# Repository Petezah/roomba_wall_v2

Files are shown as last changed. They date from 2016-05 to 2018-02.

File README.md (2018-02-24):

# roomba_wall_v2

An AVR device, based on ATTiny85, to transmit a virtual wall signal for an iRobot Roomba

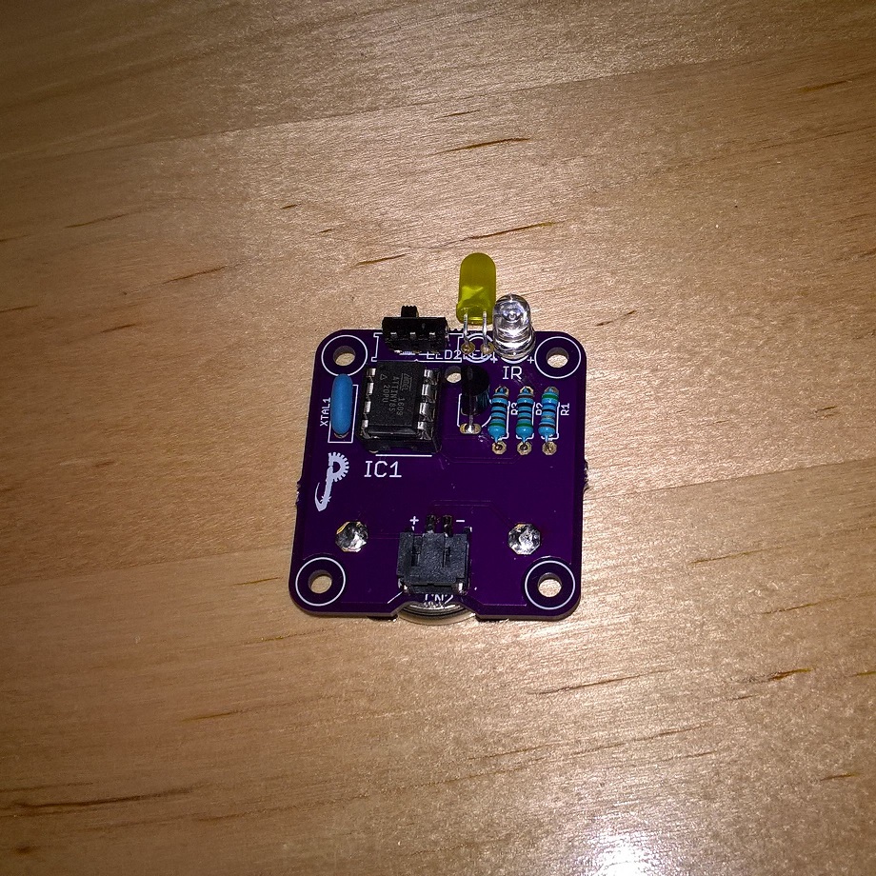
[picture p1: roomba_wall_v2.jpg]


## Folder layout

* /firmware
  * Source for the ATTiny85 firmware
* /hardware
  * Files describing the board layout, etc
* /christmas_tree_barrier
  * Files describing the board layout for the Christmas tree barrier variation

## Building

### Prerequisites for "happy path":

* Raspberry Pi configured with BCM SPI enabled
* AVR-GCC installed
  *  Easiest way to get this is 'sudo apt-get install arduino'
* Either:
  * A 6-position, dual-row IDC cable (recommended)
  * Or jumpers to wire SPI bus of Raspberry Pi to the ISP pads on the finished board

### Steps

#### hardware

* Order a board based on the files in https://github.com/Petezah/roomba_wall_v2/tree/master/hardware
  * Alternately, order one directly from OSH Park here: https://oshpark.com/shared_projects/yCviCn7Z
* Purchase parts from [Mouser electronics](http://mouser.com) using the current BOM
  * Use the ones with "mouser" in their filenames
* Assemble the board--parts are all marked on the silkscreen
  * NB: The ISP header should not be soldered to the board--merely insert the header pins into the IDC cable and wedge the pins into the vias during programming

#### firmware

There are two methods to wire the board for programming:

* *Recommended way*:
  *  Order my Raspberry Pi ISP board here: https://oshpark.com/shared_projects/iYtnPahC
  *  Assemble, and use an IDC cable as described above

* Alternate way: 
  * Hook up the ISP pins on the assembled board to your Raspberry PI as follows:
    * ISP Pin 1 --> Raspberry Pi Pin 21 (MISO)
    * ISP Pin 2 --> Raspberry Pi Pin 17 (3.3V)
    * ISP Pin 3 --> Raspberry Pi Pin 23 (SCK)
    * ISP Pin 4 --> Raspberry Pi Pin 19 (MOSI)
    * ISP Pin 5 --> Raspberry Pi Pin 15 (GPIO22)
    * ISP Pin 6 --> Raspberry Pi Pin 25 (GND)

Once wiring is accomplished:
* Execute the following on the Raspberry Pi command line
  * cd firmware
  * make fuse
  * make install

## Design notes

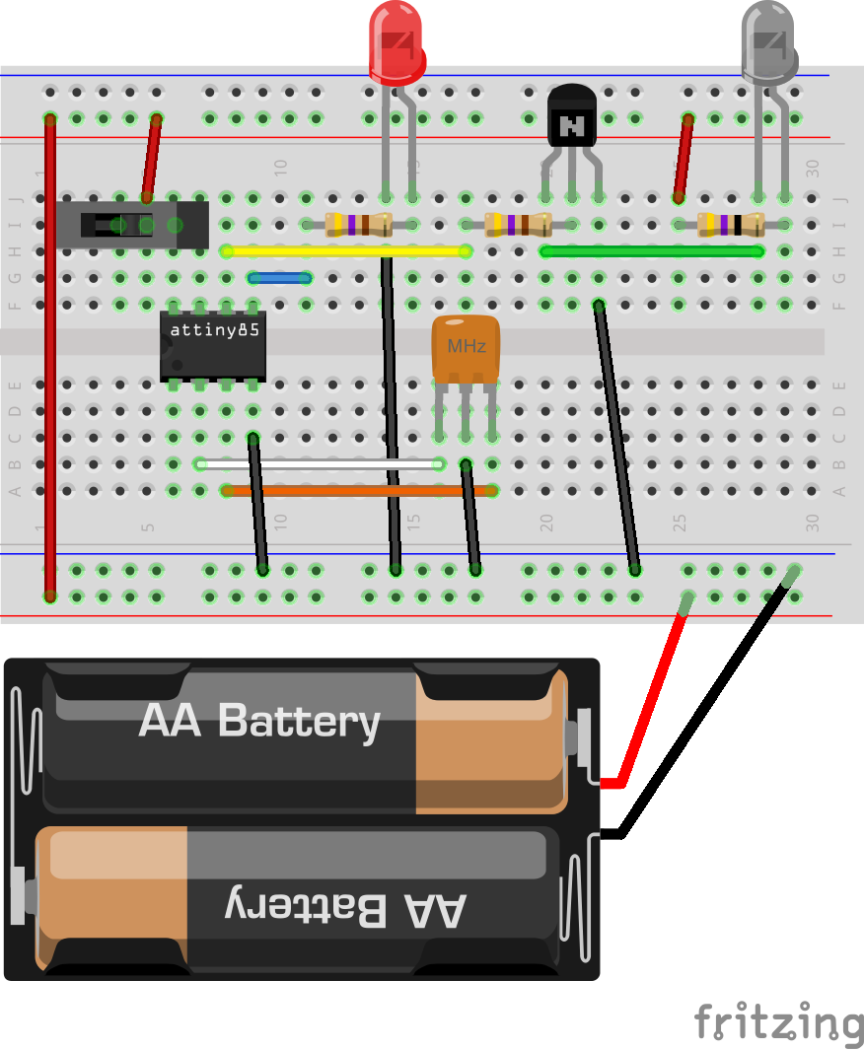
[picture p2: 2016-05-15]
misc/roomba_wall_v2_bb.png

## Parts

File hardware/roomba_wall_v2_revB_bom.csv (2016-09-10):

Mouser # | Mfr. # | Manufacturer | Desc. | RoHS | Lifecycle | Customer Part # | Order Qty. | Price (USD) | Ext.: (USD)
81-CSTLS8M00G53-A0 | CSTLS8M00G53-A0 | Murata | Resonators 8.000MHZ .5% LEADED | RoHS Compliant |  |  | 1 | $0.21 | $0.21
642-MHSS1105 | MHSS1105 | Apem | Slide Switches Microminiature slide SP DT | RoHS Compliant |  |  | 1 | $0.60 | $0.60
12BH003-GR | 12BH003-GR | Eagle Plastic Devices | Coin Cell Battery Holders CR2032 BATTERY CLIP | RoHS Compliant |  |  | 1 | $0.45 | $0.45
512-PN2222ABU | PN2222ABU | Fairchild Semiconductor | Bipolar Transistors - BJT NPN Transistor General Purpose | RoHS Compliant |  |  | 1 | $0.21 | $0.21
660-MF1/4LCT52R510J | MF1/4LCT52R510J | KOA Speer | Metal Film Resistors - Through Hole 1/4 WATT 51 OHM 5% | RoHS Compliant |  |  | 1 | $0.10 | $0.10
660-MF1/4LCT52R561J | MF1/4LCT52R561J | KOA Speer | Metal Film Resistors - Through Hole 1/4 WATT 560 OHM 5% | RoHS Compliant |  |  | 2 | $0.10 | $0.20
941-C566DBFECU0W0351 | C566D-BFE-CU0W0351 | Cree, Inc. | Standard LEDs - Through Hole Blue Oval | RoHS Compliant |  |  | 1 | $0.19 | $0.19
538-10-89-7062 | 10-89-7062 | Molex | Headers & Wire Housings VERT BRKAWAY HDR 6P CN | RoHS Compliant |  |  | 1 | $0.70 | $0.70
782-TSAL6100 | TSAL6100 | Vishay | Infrared Emitters 10 Degree 40mW | RoHS Compliant |  |  | 1 | $0.48 | $0.48
556-ATTINY85-20PU | ATTINY85-20PU | Atmel | 8-bit Microcontrollers - MCU 8kB Flash 0.512kB EEPROM 6 I/O Pins | RoHS Compliant |  |  | 1 | $2.35 | $2.35
485-1769 | 1769 | Adafruit | Adafruit Accessories JST-PH 2-pin SMT Right Angle Connect | RoHS Compliant |  |  | 1 | $0.75 | $0.75

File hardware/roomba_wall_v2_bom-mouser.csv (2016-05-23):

Roomba Virtual Wall v2 - Rev A
Mouser # | Mfr. # | Manufacturer | Desc. | RoHS | Lifecycle | Customer Part # | Order Qty. | Price (USD) | Ext.: (USD)
81-CSTLS8M00G53-A0 | CSTLS8M00G53-A0 | Murata | Resonators 8.000MHZ .5% LEADED | RoHS Compliant |  |  | 1 | $0.23 | $0.23
642-MHSS1105 | MHSS1105 | Apem | Slide Switches Microminiature slide SP DT | RoHS Compliant |  |  | 1 | $0.60 | $0.60
658-CR2032 | CR2032 | Panasonic | Coin Cell Battery 3V 20X3.2MM 225mAH | Not Applicable |  |  | 1 | $0.33 | $0.33
12BH003-GR | 12BH003-GR | Eagle Plastic Devices | Coin Cell Battery Holders CR2032 BATTERY CLIP | RoHS Compliant |  |  | 1 | $0.45 | $0.45
512-PN2222ABU | PN2222ABU | Fairchild Semiconductor | Bipolar Transistors - BJT NPN Transistor General Purpose | RoHS Compliant |  |  | 1 | $0.21 | $0.21
660-MF1/4LCT52R510J | MF1/4LCT52R510J | KOA Speer | Metal Film Resistors - Through Hole 1/4 WATT 51 OHM 5% | RoHS Compliant |  |  | 1 | $0.10 | $0.10
660-MF1/4LCT52R561J | MF1/4LCT52R561J | KOA Speer | Metal Film Resistors - Through Hole 1/4 WATT 560 OHM 5% | RoHS Compliant |  |  | 2 | $0.10 | $0.20
941-C566DBFECU0W0351 | C566D-BFE-CU0W0351 | Cree, Inc. | Standard LEDs - Through Hole Blue Oval | RoHS Compliant |  |  | 1 | $0.19 | $0.19
604-WP7113GD | WP7113GD | Kingbright | Standard LEDs - Through Hole GREEN DIFFUSED | RoHS Compliant |  |  | 1 | $0.14 | $0.14
538-10-89-7062 | 10-89-7062 | Molex | Headers & Wire Housings VERT BRKAWAY HDR 6P CN | RoHS Compliant |  |  | 1 | $0.67 | $0.67
782-TSAL6100 | TSAL6100 | Vishay | Infrared Emitters 10 Degree 40mW | RoHS Compliant |  |  | 1 | $0.48 | $0.48
556-ATTINY85-20PU | ATTINY85-20PU | Atmel | 8-bit Microcontrollers - MCU 8kB Flash 0.512kB EEPROM 6 I/O Pins | RoHS Compliant |  |  | 1 | $1.67 | $1.67
485-1769 | 1769 | Adafruit | Adafruit Accessories JST-PH 2-pin SMT Right Angle Connect | RoHS Compliant |  |  | 1 | $0.75 | $0.75
490-PJ-002A | PJ-002A | CUI Inc. | DC Power Connectors Power Jacks | RoHS Compliant | New At Mouser |  | 1 | $0.93 | $0.93

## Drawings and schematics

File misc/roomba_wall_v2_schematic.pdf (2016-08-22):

A

1 | 2 | 3 | 4 | 5 | 6 | 7 | 8

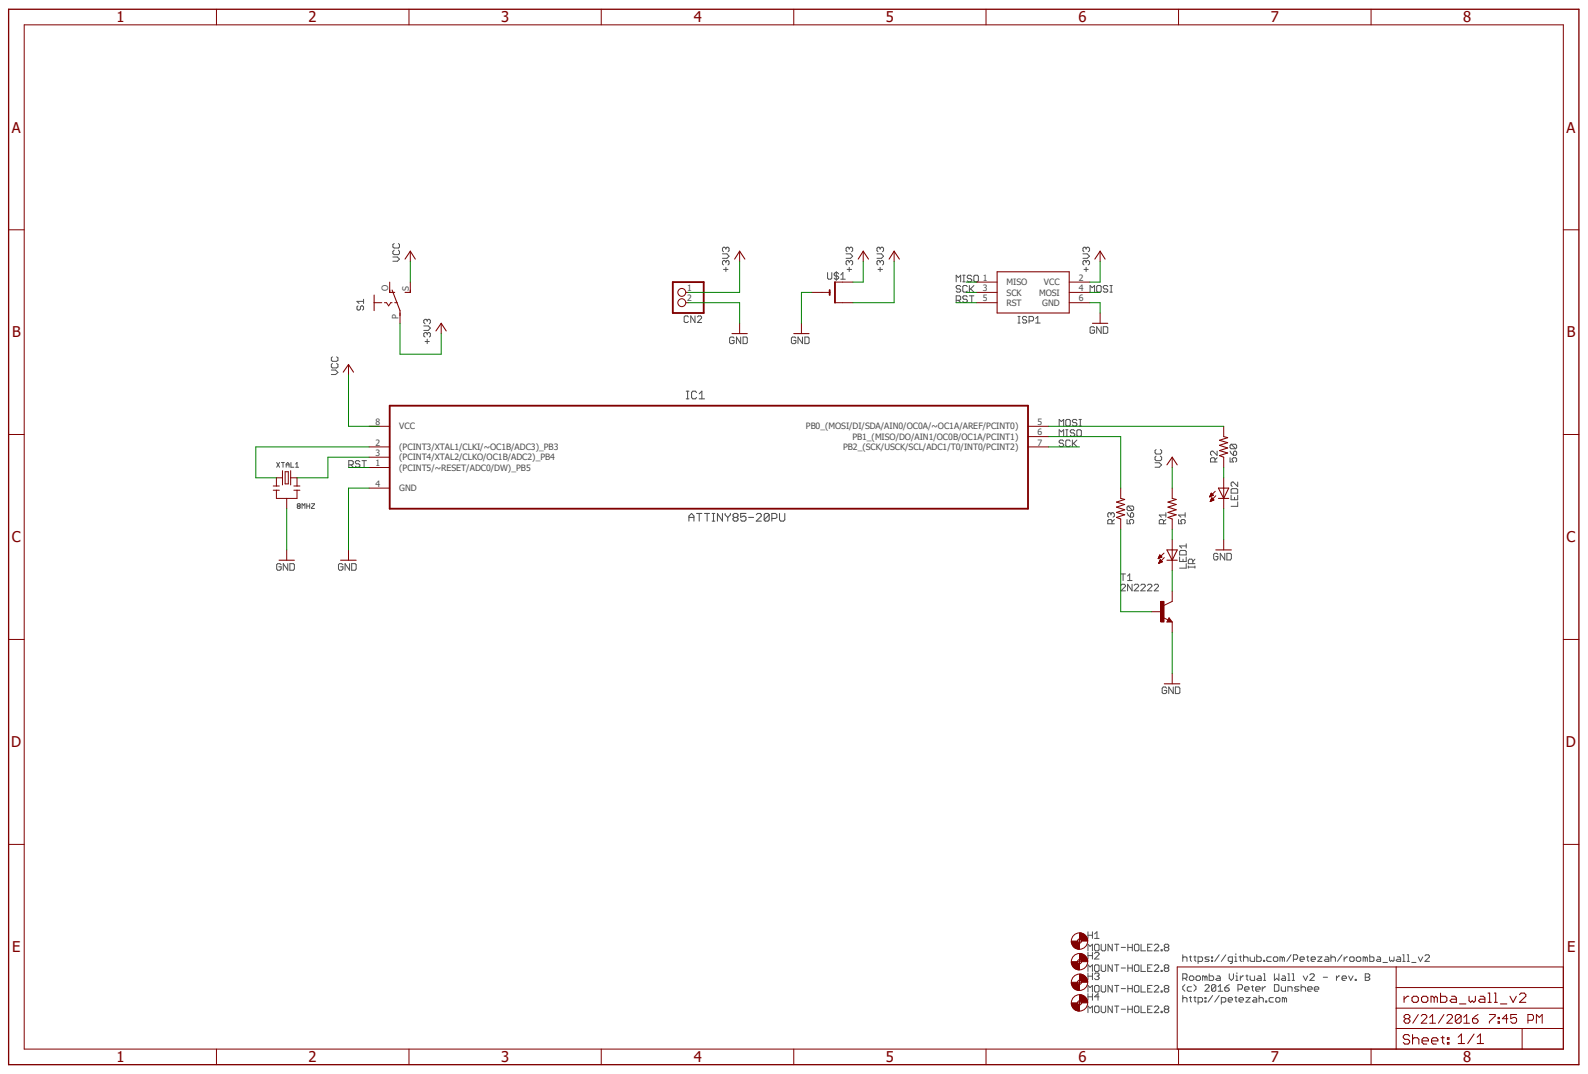
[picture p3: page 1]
VCC 8; (PCINT3/XTAL1/CLKI/~OC1B/ADC3)_PB3 2 (PCINT4/XTAL2/CLKO/OC1B/ADC2)_PB4 3; (PCINT5/~RESET/ADC0/DW)_PB5 1; GND 4; PB0_(MOSI/DI/SDA/AIN0/OC0A/~OC1A/AREF/PCINT0); 5 PB1_(MISO/DO/AIN1/OC0B/OC1A/PCINT1); 6 PB2_(SCK/USCK/SCL/ADC1/T0/INT0/PCINT2); 7 MISO 1; SCK 3; RST 5; GND; 6 MOSI; 4 VCC

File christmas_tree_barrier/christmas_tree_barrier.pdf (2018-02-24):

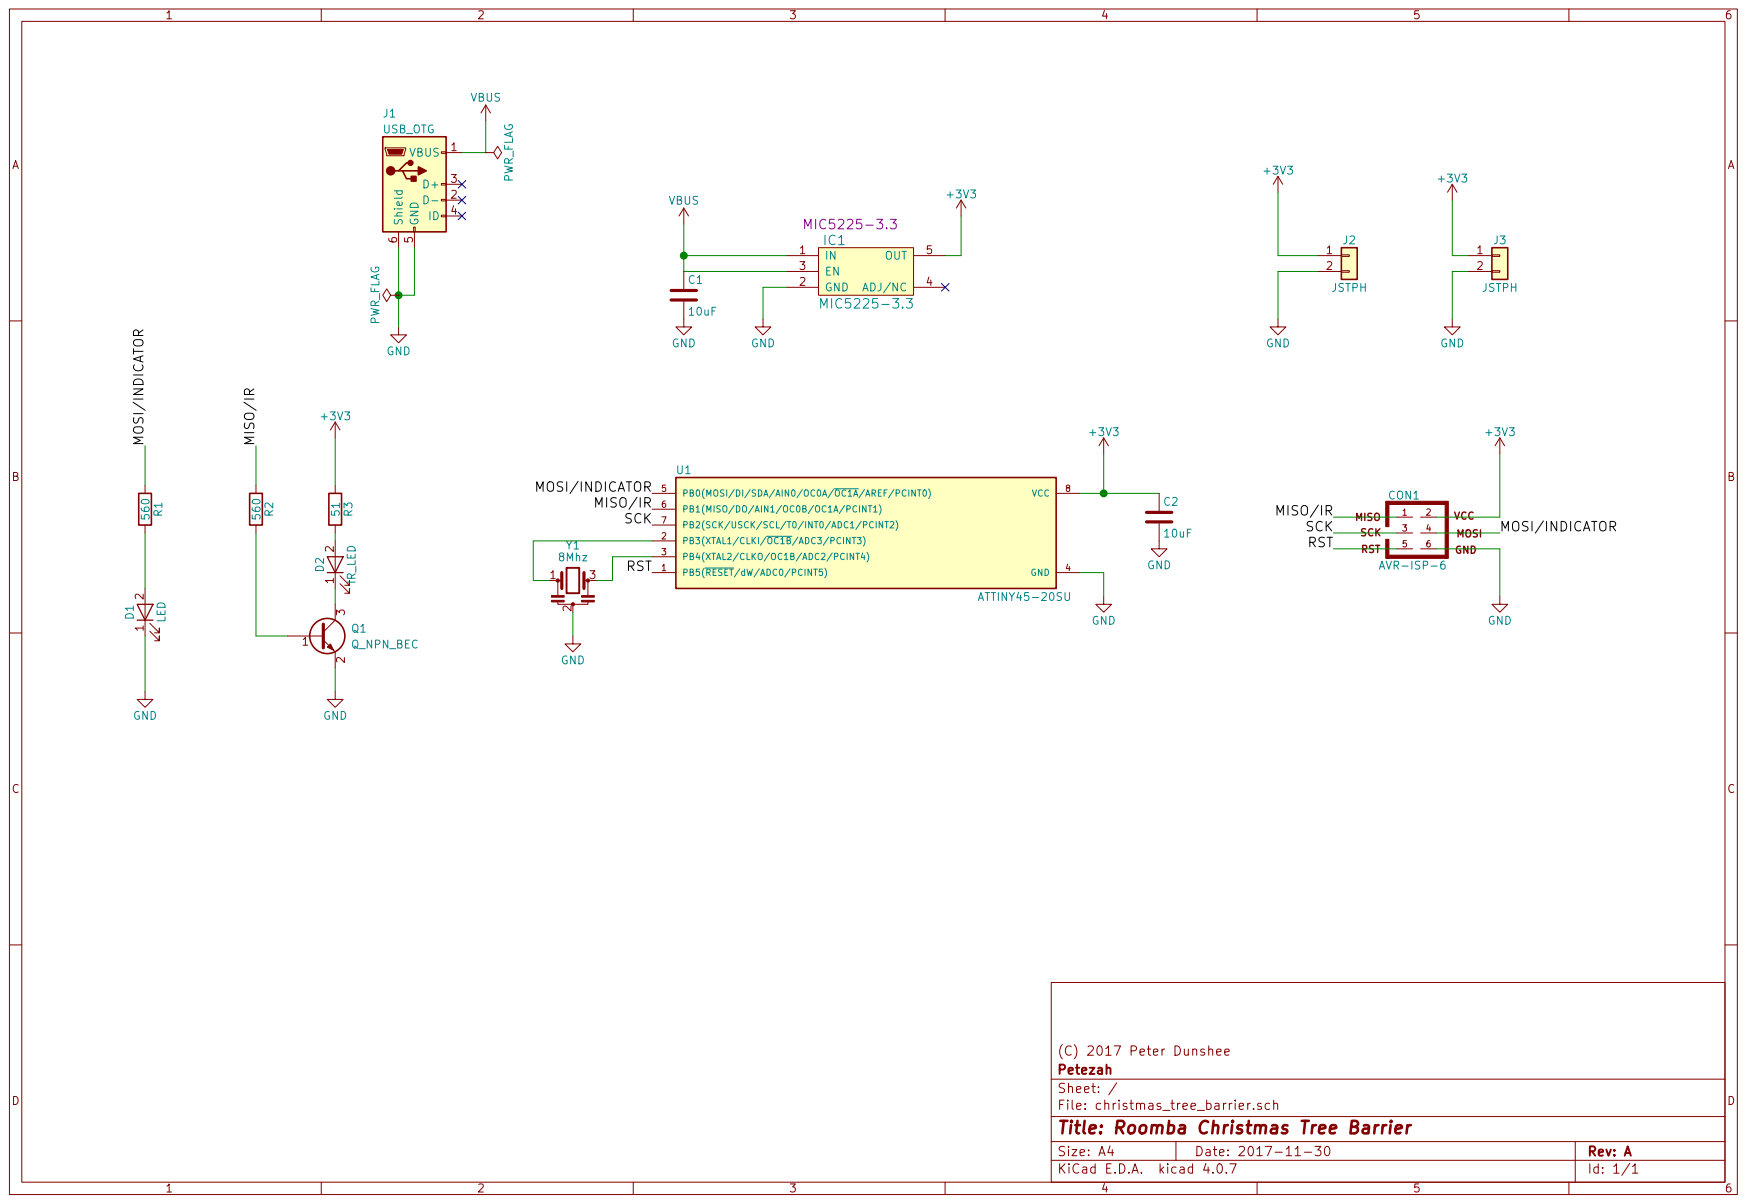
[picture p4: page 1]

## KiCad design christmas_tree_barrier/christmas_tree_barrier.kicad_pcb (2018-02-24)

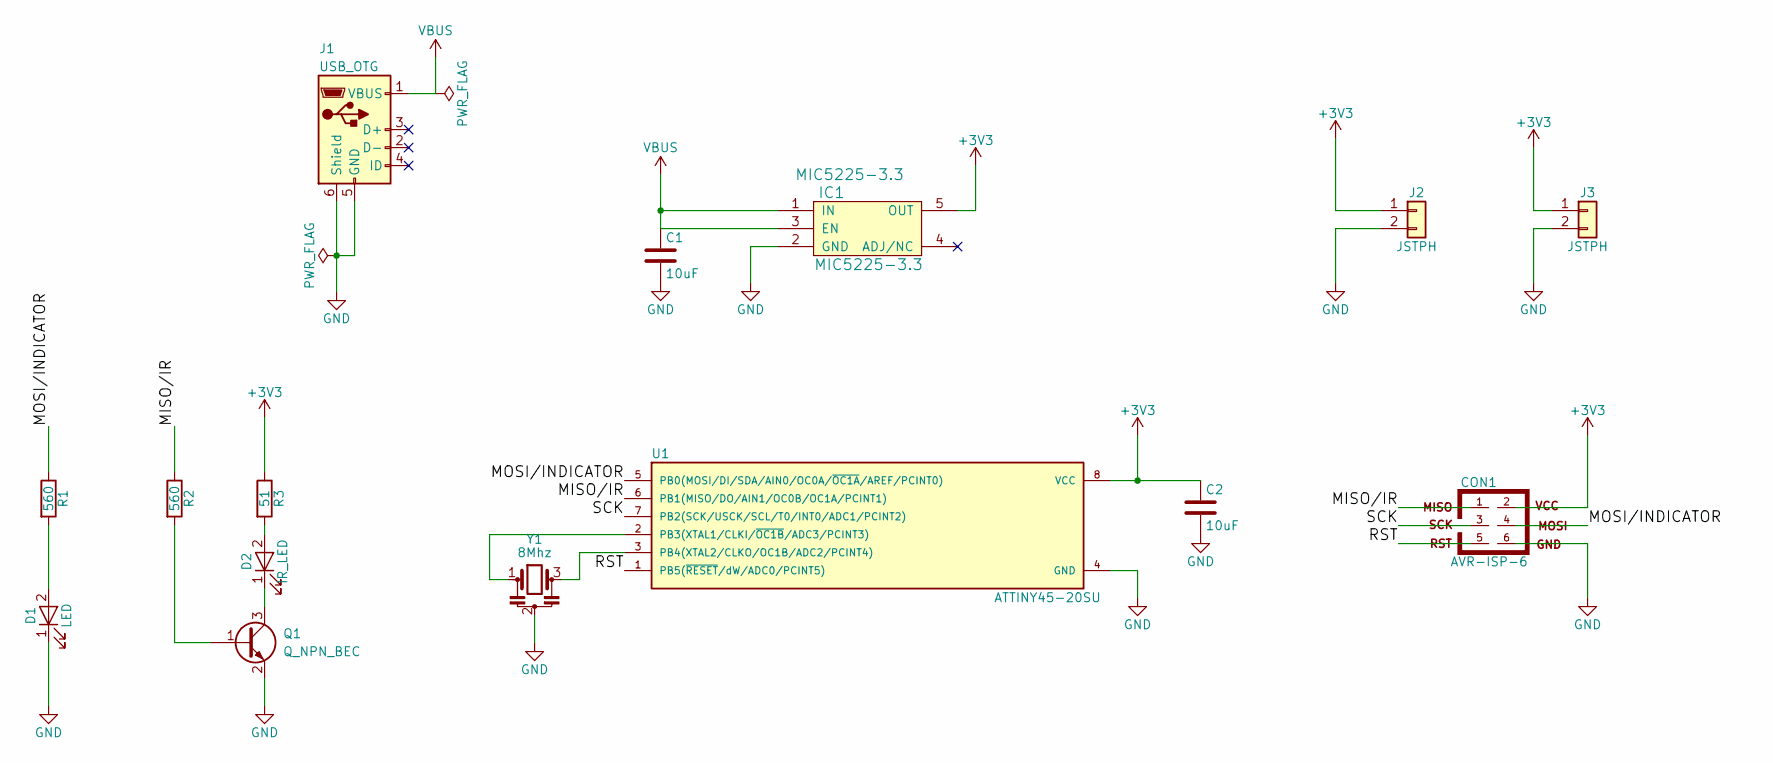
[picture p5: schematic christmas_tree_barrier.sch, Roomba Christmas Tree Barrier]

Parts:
C1, C2: 10uF; C_1206
CON1: AVR-ISP-6; Pin_Header_Straight_2x03_Pitch2.54mm
D1: LED; LED_1206
D2: IR_LED; LED_0603_HandSoldering
IC1: MIC5225-3.3; SOT-23-5_HandSoldering; mfr# MIC5225-3.3
J1: USB_OTG; USB_Micro-B_10103594-0001LF
J2, J3: JSTPH; JST_PH_B2B-PH-SM4-TB_02x2.00mm_Straight
Q1: Q_NPN_BEC; SOT-23_Handsoldering
R1, R2: 560; R_1206
R3: 51; R_1206
U1: ATTINY45-20SU; SOIC-8_5.35x5.40mm_Pitch1.27mm
Y1: 8Mhz; Resonator_SMD_muRata_CSTCE_G-3pin_3.0x0.7mm

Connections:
+3V3: C2.1, CON1.2, IC1.5 (OUT), J2.1, J3.1, R3.1, U1.8 (VCC)
/MISO/IR: CON1.1, R2.1, U1.6 (PB1(MISO/DO/AIN1/OC0B/OC1A/PCINT1))
/MOSI/INDICATOR: CON1.4, R1.1, U1.5 (PB0(MOSI/DI/SDA/AIN0/OC0A/~OC1A~/AREF/P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)
/RST: CON1.5, U1.1 (PB5(~RESET~/dW/ADC0/PCINT5))
/SCK: CON1.3, U1.7 (PB2(SCK/USCK/SCL/T0/INT0/ADC1/PCINT2))
GND: C1.2, C2.2, CON1.6, D1.1 (K), IC1.2 (GND), J1.5 (GND), J1.6 (Shield), J2.2, J3.2, Q1.2 (E), U1.4 (GND), Y1.2
unnamed: D1.2 (A), R1.2
unnamed: D2.1 (K), Q1.3 (C)
unnamed: D2.2 (A), R3.2
unnamed: Q1.1 (B), R2.2
unnamed: U1.2 (PB3(XTAL1/CLKI/~OC1B~/ADC3/PCINT3)), Y1.1
unnamed: U1.3 (PB4(XTAL2/CLKO/OC1B/ADC2/PCINT4)), Y1.3
VBUS: C1.1, IC1.1 (IN), IC1.3 (EN), J1.1 (VBUS)

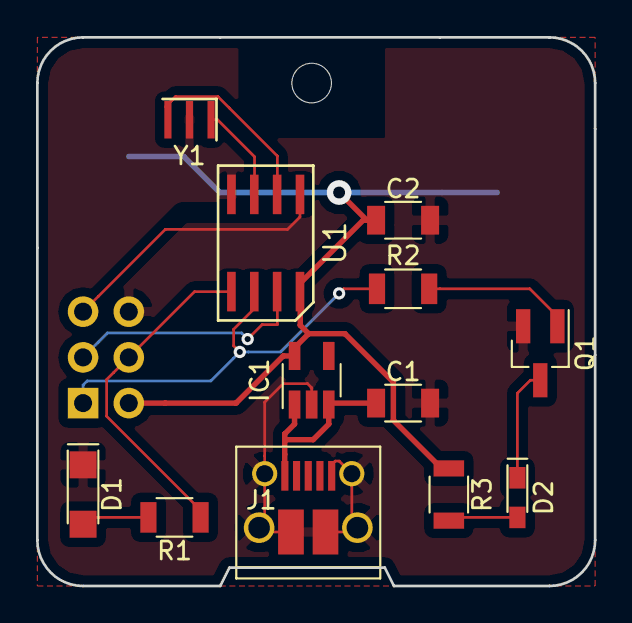
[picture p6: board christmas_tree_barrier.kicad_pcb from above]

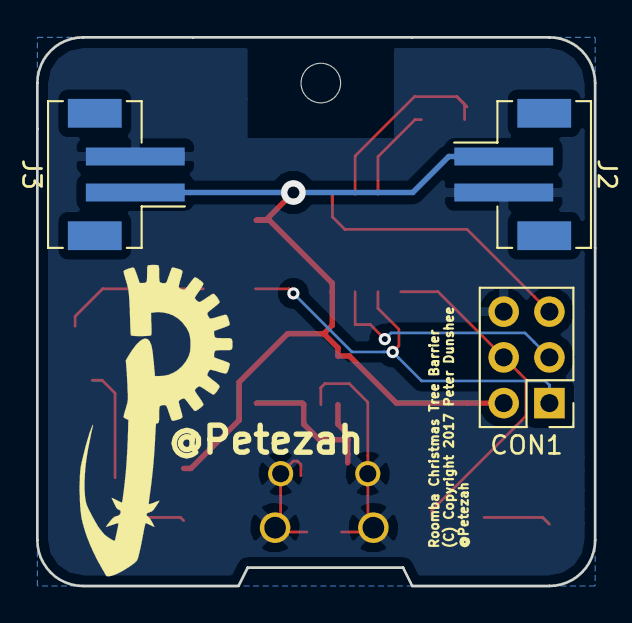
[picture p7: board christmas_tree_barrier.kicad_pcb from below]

Board: 2 copper layers, 31.0 x 30.5 mm, 15 parts (3 on the bottom side), 13 nets.

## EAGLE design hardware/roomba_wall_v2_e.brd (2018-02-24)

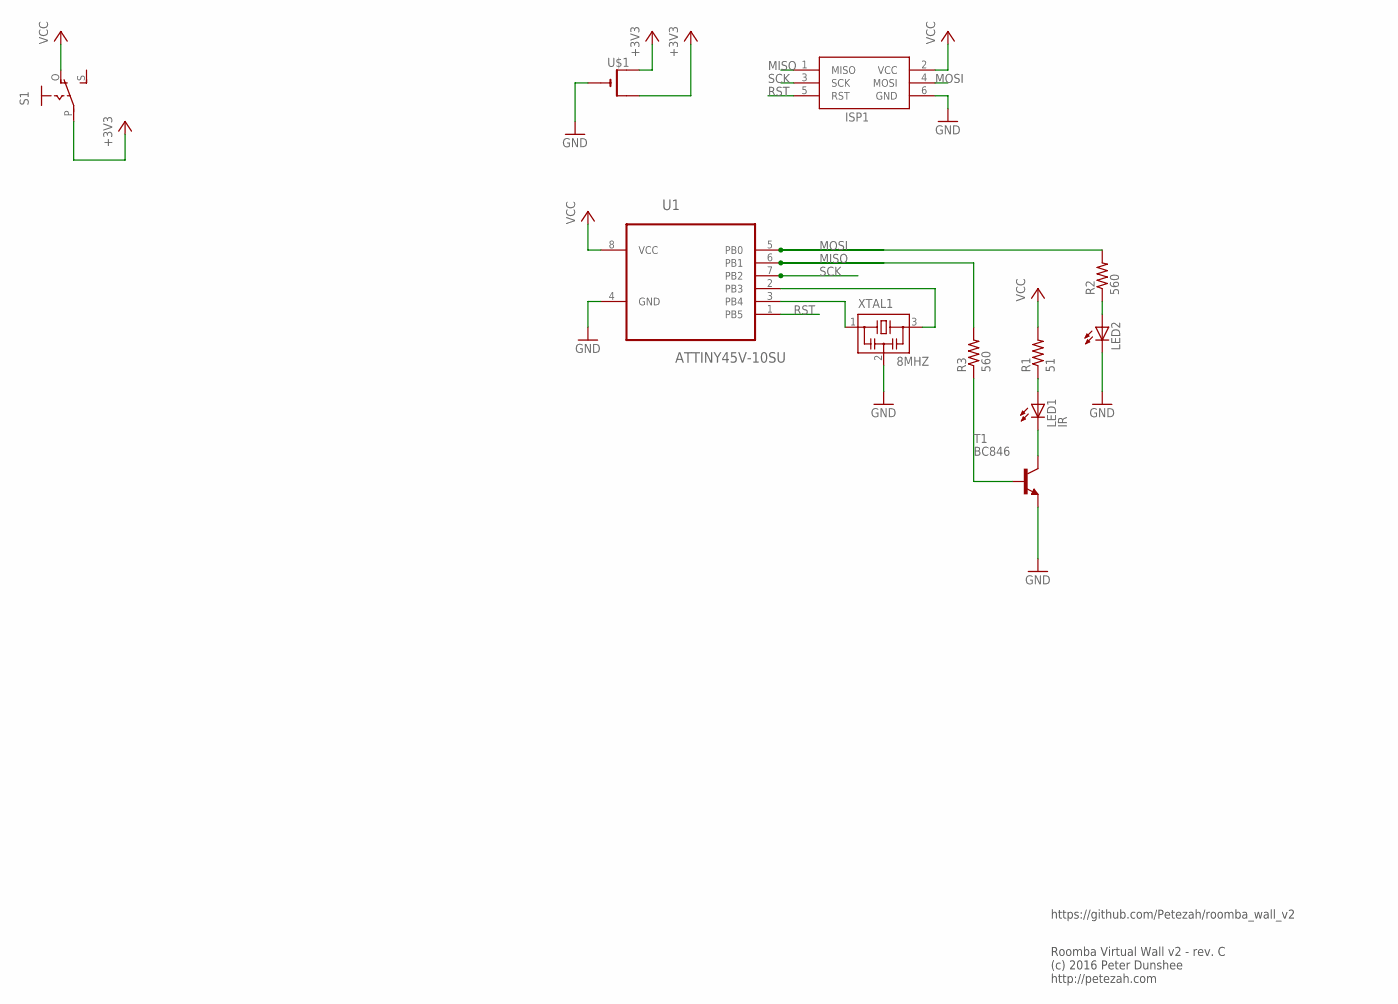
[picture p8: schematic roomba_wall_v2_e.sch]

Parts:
ISP1: AVRISP-6; AVRISP
LED1: IR; CHIPLED_0603
LED2: LEDCHIPLED_1206; CHIPLED_1206
R1: 51; R1206
R2, R3: 560; R1206
S1: EG1218S; EG1218
T1: BC846; SOT23
U1: ATTINY45V-10SU; SOIC127P798X216-8N
U$1: CR2032THM; CR2032-THRU
XTAL1: 8MHZ; CSTCR6M

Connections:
+3V3: S1.P, U$1.+1 (+), U$1.+2 (+1)
GND: ISP1.6 (GND), LED2.C, T1.2 (E), U1.4 (GND), U$1.-, XTAL1.2
MISO: ISP1.1 (MISO), R3.2, U1.6 (PB1)
MOSI: ISP1.4 (MOSI), R2.2, U1.5 (PB0)
unnamed: U1.3 (PB4), XTAL1.1
unnamed: U1.2 (PB3), XTAL1.3
unnamed: LED1.A, R1.1
unnamed: LED1.C, T1.3 (C)
unnamed: R3.1, T1.1 (B)
unnamed: LED2.A, R2.1
RST: ISP1.5 (RST), U1.1 (PB5)
SCK: ISP1.3 (SCK), U1.7 (PB2)
VCC: ISP1.2 (VCC), R1.2, S1.O, U1.8 (VCC)

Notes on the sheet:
Roomba Virtual Wall v2 - rev. C (c) 2016 Peter Dunshee http://petezah.com
https://github.com/Petezah/roomba_wall_v2

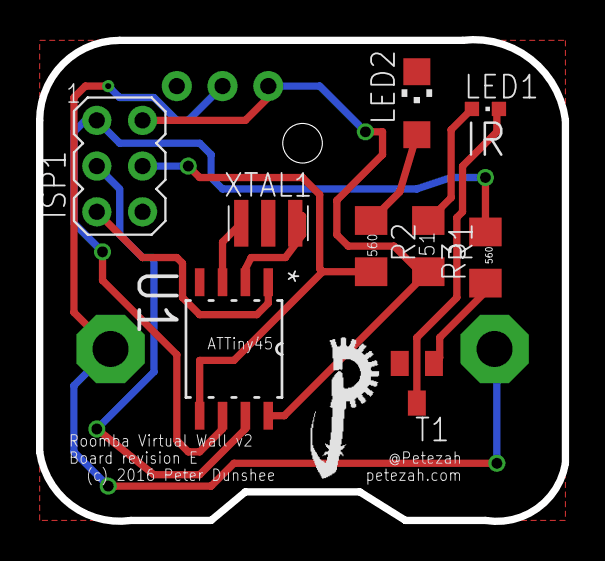
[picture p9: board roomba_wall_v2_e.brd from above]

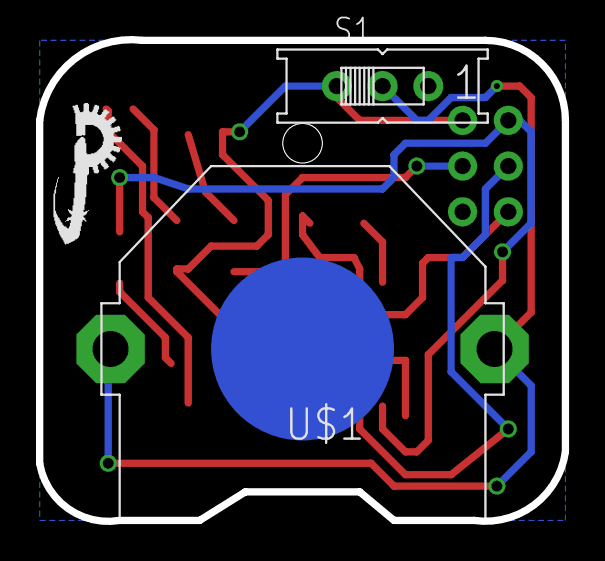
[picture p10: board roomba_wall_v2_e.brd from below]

Board: 2 copper layers, 29.2 x 26.8 mm, 13 parts (3 on the bottom side), 13 nets.

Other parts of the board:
U$2, U$3: LOGO_TINY

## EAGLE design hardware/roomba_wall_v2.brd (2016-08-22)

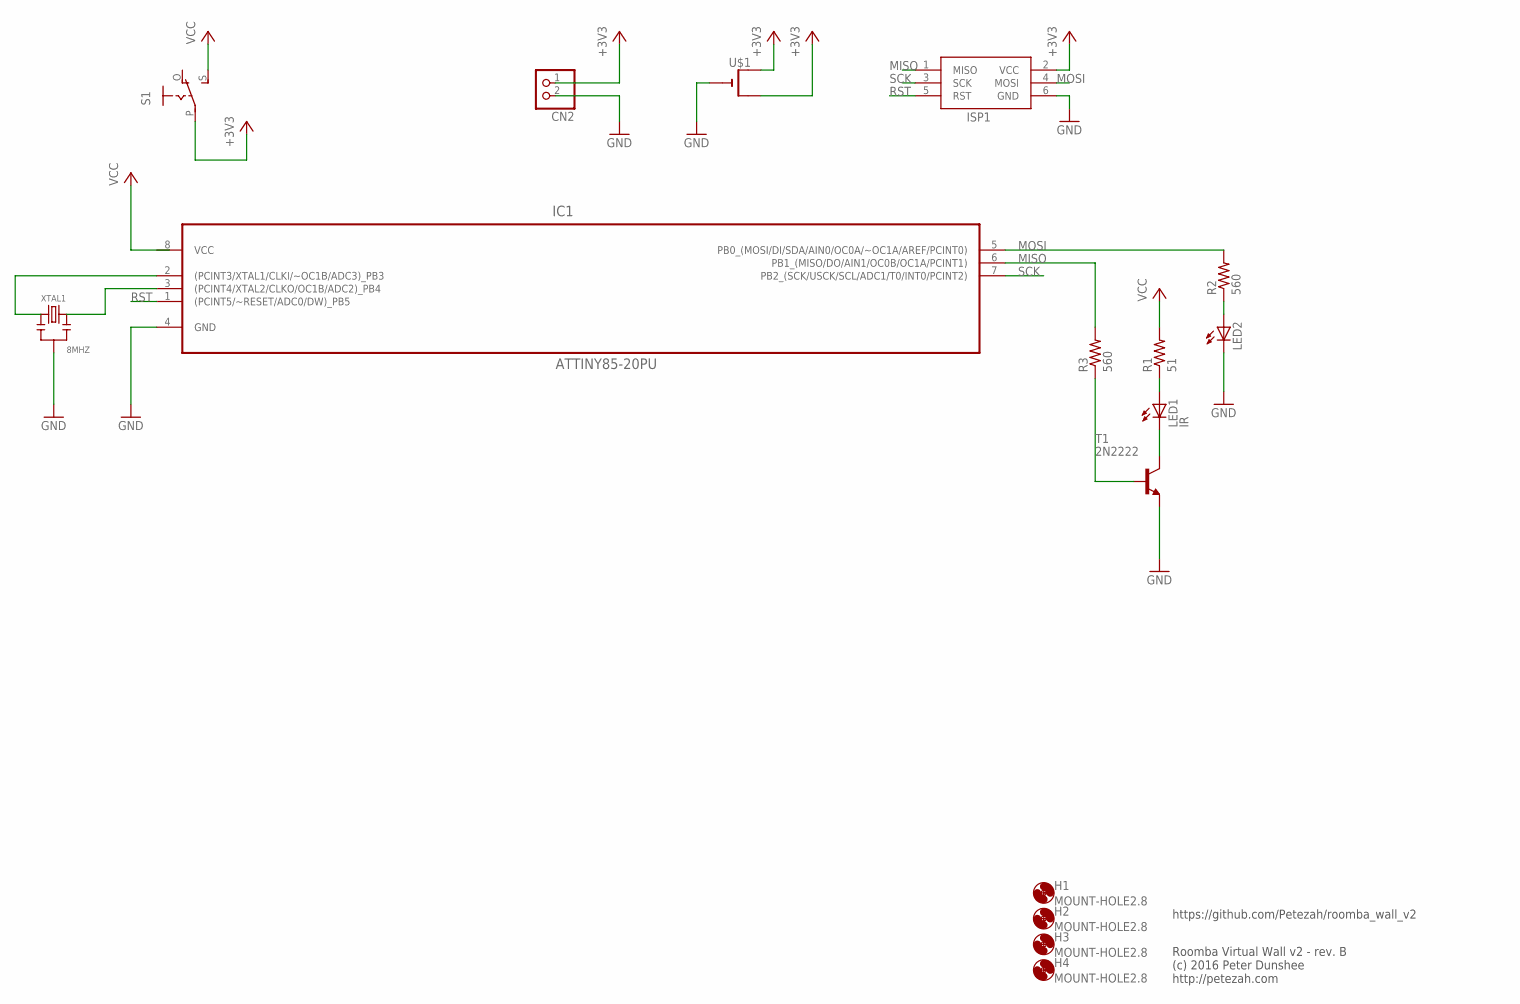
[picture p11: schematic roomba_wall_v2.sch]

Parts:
CN2: JST_2PIN-SMT-RA; JST-PH-2-SMT-RA
H1, H2, H3, H4: MOUNT-HOLE2.8; 2,8
IC1: ATTINY85-20PU; DIP254P762X533-8
ISP1: AVRISP-6; AVRISP
LED1: IR; LED3MM
LED2: LED3MM
R1: 51; 0204/7
R2, R3: 560; 0204/7
S1: EG1218S; EG1218
T1: 2N2222; TO92-EBC-OVAL
U$1: CR2032THM; CR2032-THRU
XTAL1: 8MHZ; X3-2.5-8X3X5.5MM

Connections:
+3V3: CN2.1 (2), ISP1.2 (VCC), S1.P, U$1.+1 (+), U$1.+2 (+1)
GND: CN2.2 (1), IC1.4 (GND), ISP1.6 (GND), LED2.K (C), T1.E, U$1.-, XTAL1.2
MISO: IC1.6 (PB1_(MISO/DO/AIN1/OC0B/OC1A/PCINT1)), ISP1.1 (MISO), R3.2
MOSI: IC1.5 (PB0_(MOSI/DI/SDA/AIN0/OC0A/~OC1A/AREF/P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), ISP1.4 (MOSI), R2.2
unnamed: IC1.2 ((PCINT3/XTAL1/CLKI/~OC1B/ADC3)_PB3), XTAL1.1
unnamed: IC1.3 ((PCINT4/XTAL2/CLKO/OC1B/ADC2)_PB4), XTAL1.3
unnamed: LED1.A, R1.1
unnamed: LED1.K (C), T1.C
unnamed: R3.1, T1.B
unnamed: LED2.A, R2.1
RST: IC1.1 ((PCINT5/~RESET/ADC0/DW)_PB5), ISP1.5 (RST)
SCK: IC1.7 (PB2_(SCK/USCK/SCL/ADC1/T0/INT0/PCINT2)), ISP1.3 (SCK)
VCC: IC1.8 (VCC), R1.2, S1.S

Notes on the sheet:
Roomba Virtual Wall v2 - rev. B (c) 2016 Peter Dunshee http://petezah.com
https://github.com/Petezah/roomba_wall_v2

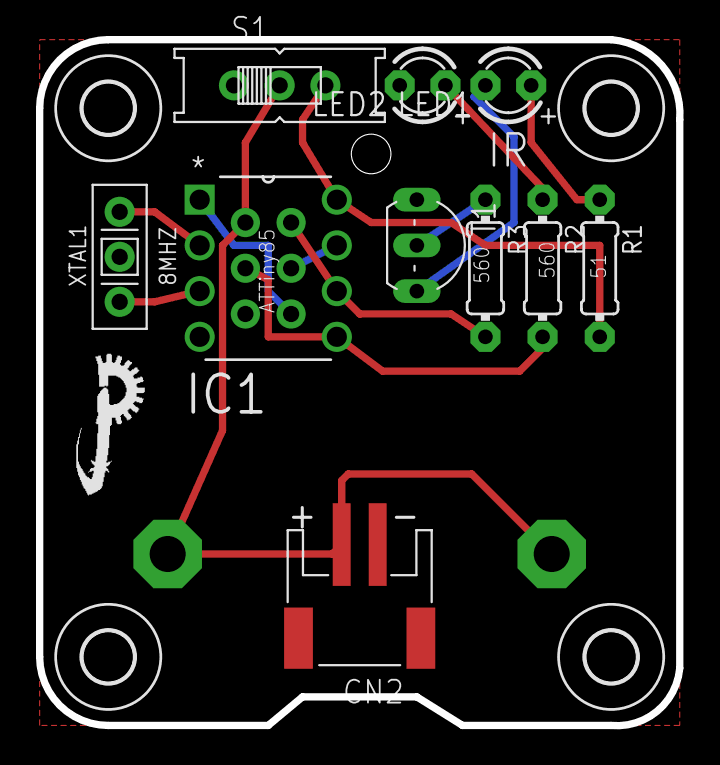
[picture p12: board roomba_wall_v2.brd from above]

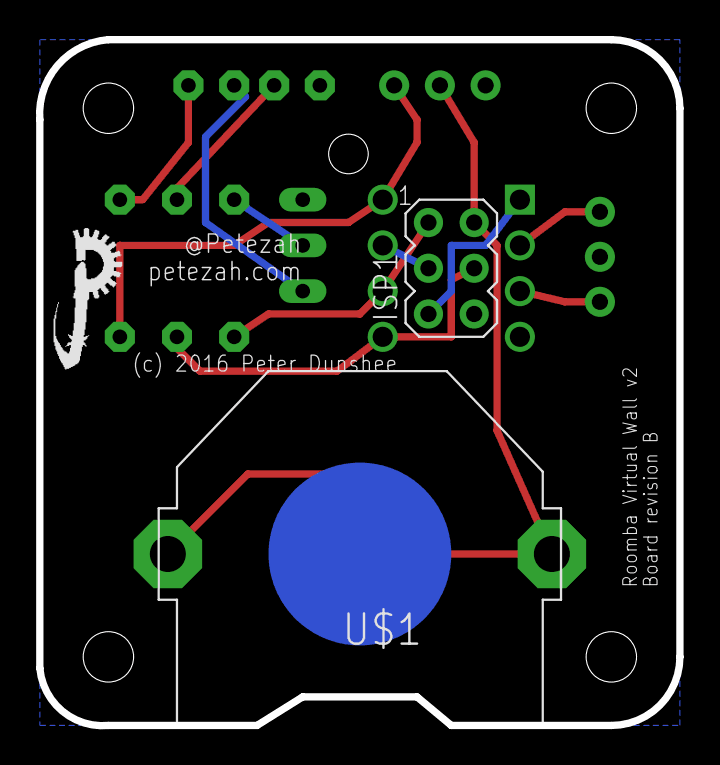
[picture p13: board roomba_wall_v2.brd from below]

Board: 2 copper layers, 35.6 x 38.1 mm, 18 parts (3 on the bottom side), 13 nets.

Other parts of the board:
U$2, U$3: LOGO_TINY

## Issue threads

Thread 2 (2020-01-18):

Dependency Listing

Plasmarobo, 2020-01-18:
Just noticing that this depends on WiringPi which isn't installed by default.
I was able to find it with a bit of googling, but it might be nice to add it to the dependencies section, it doesn't seem to be installed on raspbian-lite by default!

```
sudo apt-get install wiringpi
```

Plasmarobo, 2020-01-18:
Also worth it to note that wiringpi seems to be no longer supported at all on the Pi Zeros (all I've checked). At least it didn't work for me.

I modified the makefile to compensate:
```
MCU=attiny85 #45
AVRDUDEMCU=t85 #t45
SYSCLOCK=8000000
CC=/usr/bin/avr-gcc
CFLAGS=-g -Os -Wall -mcall-prologues -mmcu=$(MCU) -DF_CPU=$(SYSCLOCK) -I./
OBJ2HEX=/usr/bin/avr-objcopy
AVRDUDE=/usr/bin/avrdude
AVRSIZE=/usr/bin/avr-size
SOURCES=main.cpp roomba_send.cpp simple_ir.cpp
TARGET=roomba_wall_v2
SETUP_RST=echo "22" > /sys/class/gpio/export; echo "out" > /sys/class/gpio/gpio22/direction
SET_RST_HIGH=echo "1" > /sys/class/gpio/gpio22/value
SET_RST_LOW=echo "0" > /sys/class/gpio/gpio22/value

all :
        $(CC) $(CFLAGS) $(SOURCES) -o $(TARGET)
        $(AVRSIZE) $(TARGET)
        $(OBJ2HEX) -R .eeprom -O ihex $(TARGET) $(TARGET).hex
        rm -f $(TARGET)

install : all
        $(SETUP_RST)
        $(SET_RST_HIGH)
        sleep 1
        $(SET_RST_LOW)
        sleep 1
        sudo $(AVRDUDE) -p $(AVRDUDEMCU) -P /dev/spidev0.0 -c linuxspi -b 10000 -U flash:w:$(TARGET).hex
        $(SET_RST_HIGH)

noreset : all
        sudo $(AVRDUDE) -p $(AVRDUDEMCU) -P /dev/spidev0.0 -c linuxspi -b 10000 -U flash:w:$(TARGET).hex

fuse :
        $(SETUP_RST)
        $(SET_RST_HIGH)
        sleep 1
        $(SET_RST_LOW)
        sleep 1
        sudo $(AVRDUDE) -p $(AVRDUDEMCU) -P /dev/spidev0.0 -c linuxspi -b 10000 -U lfuse:w:0xfd:m -U hfuse:w:0xdf:m -U efuse:w:0xff:m
        $(SET_RST_HIGH)

clean :
        rm -f *.hex *.obj *.o
```

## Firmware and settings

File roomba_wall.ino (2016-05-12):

/*
roomba_wall.ino
A simple sketch to broadcast a "virtual wall" signal for an iRobot Roomba,
which also blinks a status LED when active.  Based on a sketch snippet by
probono (credited below), simplified for use on the ATTiny85, and modified slightly.

Changelog:
v.0.2: 5-10-2016 Peter Dunshee <peterdun@exmsft.com>
	Simplified code for transmitting only Virtual Wall signal and removed UART support to run on ATTiny85
	Added status LED

v.0.1: 2013 probono
	Initial release, Roomba transmit code--general purpose via UART commands
*/
/*

Send infrared commands from the Arduino to the iRobot Roomba
by probono

2013-03-17 Initial release

Copyright (c) 2013 by probono
All rights reserved.

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
1. Redistributions of source code must retain the above copyright notice, this
list of conditions and the following disclaimer.
2. Redistributions in binary form must reproduce the above copyright notice,
this list of conditions and the following disclaimer in the documentation
and/or other materials provided with the distribution.

THIS SOFTWARE IS PROVIDED BY THE COPYRIGHT HOLDERS AND CONTRIBUTORS "AS IS" AND
ANY EXPRESS OR IMPLIED WARRANTIES, INCLUDING, BUT NOT LIMITED TO, THE IMPLIED
WARRANTIES OF MERCHANTABILITY AND FITNESS FOR A PARTICULAR PURPOSE ARE
DISCLAIMED. IN NO EVENT SHALL THE COPYRIGHT OWNER OR CONTRIBUTORS BE LIABLE FOR
ANY DIRECT, INDIRECT, INCIDENTAL, SPECIAL, EXEMPLARY, OR CONSEQUENTIAL DAMAGES
(INCLUDING, BUT NOT LIMITED TO, PROCUREMENT OF SUBSTITUTE GOODS OR SERVICES;
LOSS OF USE, DATA, OR PROFITS; OR BUSINESS INTERRUPTION) HOWEVER CAUSED AND
ON ANY THEORY OF LIABILITY, WHETHER IN CONTRACT, STRICT LIABILITY, OR TORT
(INCLUDING NEGLIGENCE OR OTHERWISE) ARISING IN ANY WAY OUT OF THE USE OF THIS
SOFTWARE, EVEN IF ADVISED OF THE POSSIBILITY OF SUCH DAMAGE.

IR Remote Control
129 Left
130 Forward
131 Right
132 Spot
133 Max
134 Small
135 Medium
136 Large / Clean
137 Stop
138 Power
139 Arc Left
140 Arc Right
141 Stop

Scheduling Remote
142 Download
143 Seek Dock

Roomba Discovery Driveon Charger
240 Reserved
248 Red Buoy
244 Green Buoy
242 Force Field
252 Red Buoy and Green Buoy
250 Red Buoy and Force Field
246 Green Buoy and Force Field
254 Red Buoy, Green Buoy and Force

Roomba 500 Drive-on Charger
160 Reserved
161 Force Field
164 Green Buoy
165 Green Buoy and Force Field
168 Red Buoy
169 Red Buoy and Force Field
172 Red Buoy and Green Buoy
173 Red Buoy, Green Buoy and Force Field

Roomba 500 Virtual Wall
162 Virtual Wall

Roomba 500 Virtual Wall Lighthouse ###### (FIXME: not yet supported here)
0LLLL0BB
LLLL = Virtual Wall Lighthouse ID
(assigned automatically by Roomba
560 and 570 robots)
1-10: Valid ID
11: Unbound
12-15: Reserved
BB = Which Beam
00 = Fence
01 = Force Field
10 = Green Buoy
11 = Red Buoy

*/

#include <IRremote.h>
#include <avr/power.h>

IRsend irsend; // hardwired to pin 0 on ATTiny85; use a transistor to drive the IR LED for maximal range

void setup()
{
	if (F_CPU == 16000000) clock_prescale_set(clock_div_1);

	// Red-Status LED
	pinMode(4, OUTPUT);
	digitalWrite(4, LOW);
}

int i = 0;
void loop()
{
	i++;
	if (i == 0) digitalWrite(4, LOW);
	if (i == 100) digitalWrite(4, HIGH);
	if (i == 105) i = -1;

	roomba_send(162); // Virtual Wall
	delay(1000);
}

void roomba_send(int code)
{
	const int length = 8;
	unsigned int raw[length * 2];
	unsigned int one_pulse = 3000;
	unsigned int one_break = 1000;
	unsigned int zero_pulse = one_break;
	unsigned int zero_break = one_pulse;

	int arrayposition = 0;
	// Serial.println("");
	for (int counter = length - 1; counter >= 0; --counter) {
		if (code & (1 << counter)) {
			// Serial.print("1");
			raw[arrayposition] = one_pulse;
			raw[arrayposition + 1] = one_break;
		}
		else {
			// Serial.print("0");
			raw[arrayposition] = zero_pulse;
			raw[arrayposition + 1] = zero_break;
		}
		arrayposition = arrayposition + 2;
	}
	for (int i = 0; i < 3; i++) {
		irsend.sendRaw(raw, 15, 38);
		delay(50);
	}
	//Serial.println("");
}

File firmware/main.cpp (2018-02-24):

/*
 * roomba_wall_v2.cpp
 *
 * Created: 5/11/2016 9:12:04 PM
 * Author : Peter Dunshee
 */ 

#include "roomba_wall_v2.h"
#include <avr/io.h>
#include <avr/power.h>

int main(void)
{
	// Red-Status LED
	DDRB |= _BV(0);   // Set PORTB pin 4 to digital output (equivalent to pinMode(0, OUTPUT))
	PORTB &= ~_BV(0); // Pin 0 set to LOW (equivalent to digitalWrite(0, LOW))

    /* Replace with your application code */
	int i = -1;
	while (1)
	{
		i++;
		if (i == 0) PORTB |= _BV(0);// digitalWrite(4, HIGH);
		if (i == 1) PORTB &= ~_BV(0); // digitalWrite(4, LOW);
		if (i == 5) i = -1;

		roomba_send(162); // Virtual Wall
		PORTB &= ~_BV(0); // digitalWrite(4, LOW);
#ifdef ROOMBA_WALL_V2
		delay_ten_us(50000);
#else // others (eg. Christmas barrier)
		delay_ten_us(10000);
#endif
	}
}

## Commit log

2016-05-12 Reworked project for bare ATTiny85 * Moved 3rd party roomba send logic into its own file * Integrated just the portions of the IRRemote library that we need * Integrated our one Arduino dependency, w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
    [main.cpp, roomba_send.cpp, simple_ir.cpp]
2016-05-13 Trying to switch our clock over to timer 1 to free up timer 0 exclusively for pwm
2016-05-13 Simplified by eliminating the clock timing required by the wiring delay functions and instead use a hand-tuned delay function specifically for 8Mhz ATTiny85 from the TV-B-Gone project. Also inspired 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
    [main.cpp, roomba_send.cpp, simple_ir.cpp]
2016-05-15 Made a layout image of the prototype for reference. Moved hardware and firmware files into separate directories.
    [roomba_wall_v2.fzz]
2016-05-18 Rev A of schematic and pcb layout
    [roomba_wall_v2.brd, roomba_wall_v2.sch]
2016-05-18 BOM in CSV format
    [roomba_wall_v2_bom.csv]
2016-05-23 Exported more useful BOM from Mouser
    [roomba_wall_v2_bom-mouser.csv, roomba_wall_v2_bom-mouser.xls]
2016-06-05 Update readme with current instructions
2016-06-15 Doubled the IR transmit delay This is an experiment, attempting to extend the battery life of the device.
2016-06-15 Changed the timing to improve battery life again It now transmits once per second instead of once per .02 seconds. Testing the firmware with the device, it still stops the roomba. Battery life should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
2016-08-22 PCB layout, rev B 1/3 smaller, with mounting holes and cutout for the battery holder
    [roomba_wall_v2.brd, roomba_wall_v2.sch]
2016-08-22 Update schematic printout
2016-09-04 Rev C and D boards C: ATTiny85/45 in SOIC package D: ATTiny45 in TSSOP package
    [roomba_wall_v2_bom-mouser.xls, roomba_wall_v2_c.brd, roomba_wall_v2_c.sch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]
2016-09-10 Reorganize project and update BOM
    [roomba_wall_v2.brd, roomba_wall_v2.fzz, roomba_wall_v2.sch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]
2016-09-21 Updated image with picture of rev B board
2016-10-30 Rev E board SOIC ATTiny 1206 indicator LED 0603 IR LED
    Larger uC to make assembly easier than the SSOP. SMD LEDs to make the board more durable to life in the hallway.
    [roomba_wall_v2_e.brd, roomba_wall_v2_e.sch]
2017-11-26 Print out size during buildwq
2017-11-26 Latest changes to rev E Not sure what's in here; they were made a while ago and just weren't committed. This is possibly the fix to the unconnected GND on the MCU.
    [roomba_wall_v2_e.brd, roomba_wall_v2_e.sch]
2017-11-26 Starting Christmas tree barrier project
    [christmas_tree_barrier.kicad_pcb, christmas_tree_barrier.sch]
2017-11-27 Finished new schematic; started pcb layout
    [christmas_tree_barrier.kicad_pcb, christmas_tree_barrier.sch]
2017-11-28 Working on new pcb
    [christmas_tree_barrier.kicad_pcb, christmas_tree_barrier.sch]
2017-11-28 Place parts nicely
    [christmas_tree_barrier.kicad_pcb]
2017-11-28 Mostly finalize placement and outline
    [christmas_tree_barrier.kicad_pcb, christmas_tree_barrier.sch]
2017-11-29 Finished layout and routing Also just a bit of silkscreen
    [christmas_tree_barrier.kicad_pcb, christmas_tree_barrier.sch]
2017-12-01 Archive symbols and footprints
    [christmas_tree_barrier.kicad_pcb, christmas_tree_barrier.sch]
2017-12-01 Ignore KiCAD backup files
2017-12-04 Fix transistor on schematic Accidentally had a PNP instead of an NPN; doesn't change the PCB layout, I just made the mistake on the schematic.
    [christmas_tree_barrier.sch]
2018-01-03 Fix footprints SOIC-8 was wrong--body was too narrow and pads too short LEDs were unclear--cathode indicator was on top of solder mask area
    Also plotted gerbers
    [christmas_tree_barrier-B.Cu.gbr, christmas_tree_barrier-B.Mask.gbr, christmas_tree_barrier-B.Paste.gbr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]
2018-02-21 Latest PCB work
    [christmas_tree_barrier-B.Cu.gbr, christmas_tree_barrier-B.Mask.gbr, christmas_tree_barrier-B.Paste.gbr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]
2018-02-24 Latest gerber plots
    [christmas_tree_barrier-B.Cu.gbr, christmas_tree_barrier-B.Mask.gbr, christmas_tree_barrier-B.Paste.gbr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]

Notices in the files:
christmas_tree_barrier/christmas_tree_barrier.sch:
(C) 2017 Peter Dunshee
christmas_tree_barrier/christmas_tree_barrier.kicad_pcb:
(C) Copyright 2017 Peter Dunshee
